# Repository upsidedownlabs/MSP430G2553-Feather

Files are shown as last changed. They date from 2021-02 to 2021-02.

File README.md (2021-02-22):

# MSP430G2553 Feather Board

  

MSP430G2553 based Adafruit feather compatible board 🪶

| Front |  Back |
| :---: | :---: |
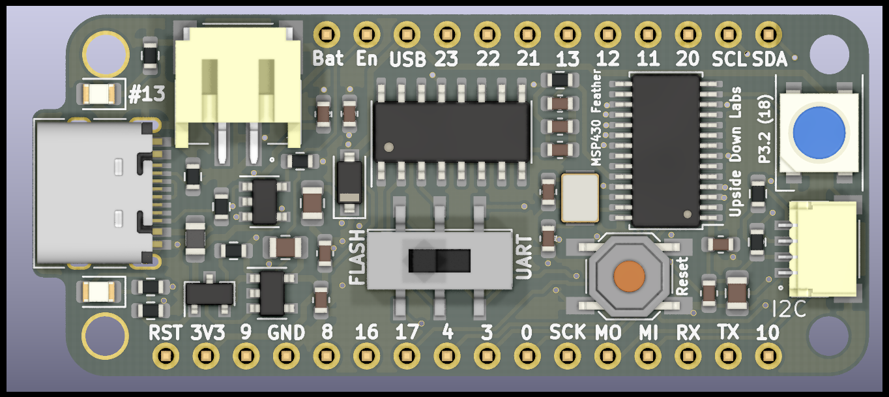
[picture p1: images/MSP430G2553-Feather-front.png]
Upside Down Labs MSP430G2553 Feather front
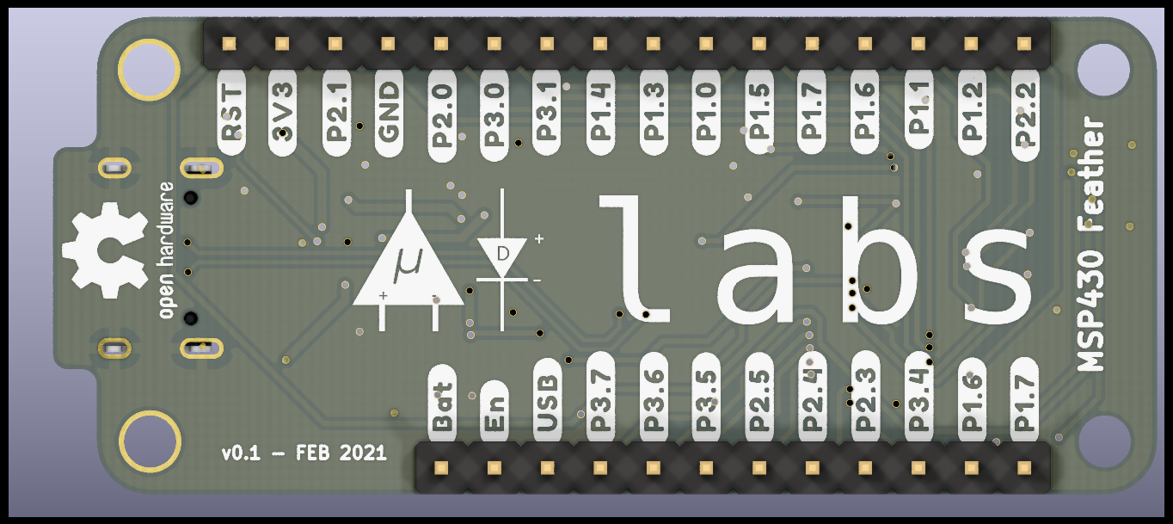
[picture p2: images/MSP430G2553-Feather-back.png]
Upside Down Labs MSP430G2553 Feather back
|   |  |

<!-- |Pinout|
| :--: |
|![Upside Down Labs MSP430G2553 Feather front](/images/MSP430G2553-Feather-Pinout.png)| -->

| Dimensions |  Schematic |
| :---: | :---: |
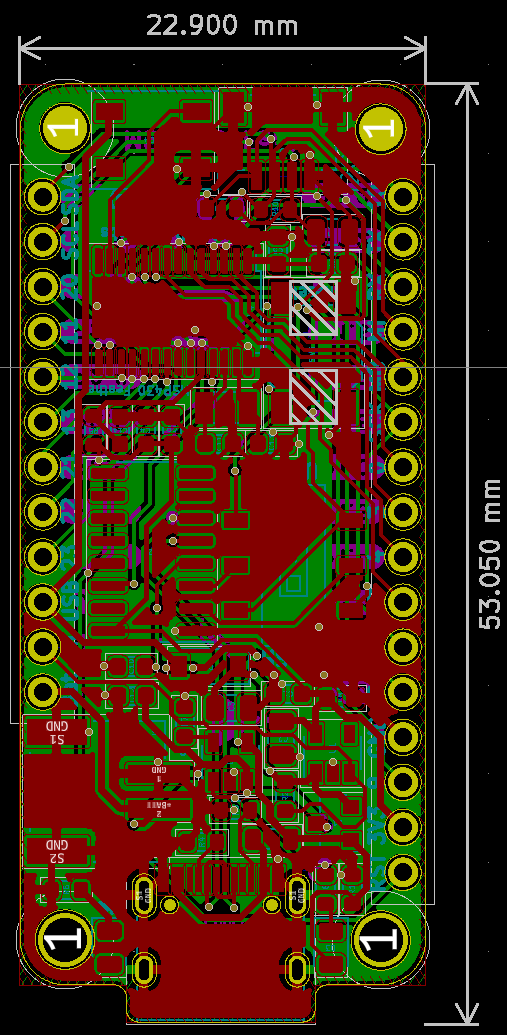
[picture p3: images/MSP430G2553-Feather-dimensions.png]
Upside Down Labs MSP430G2553 Feather dimensions
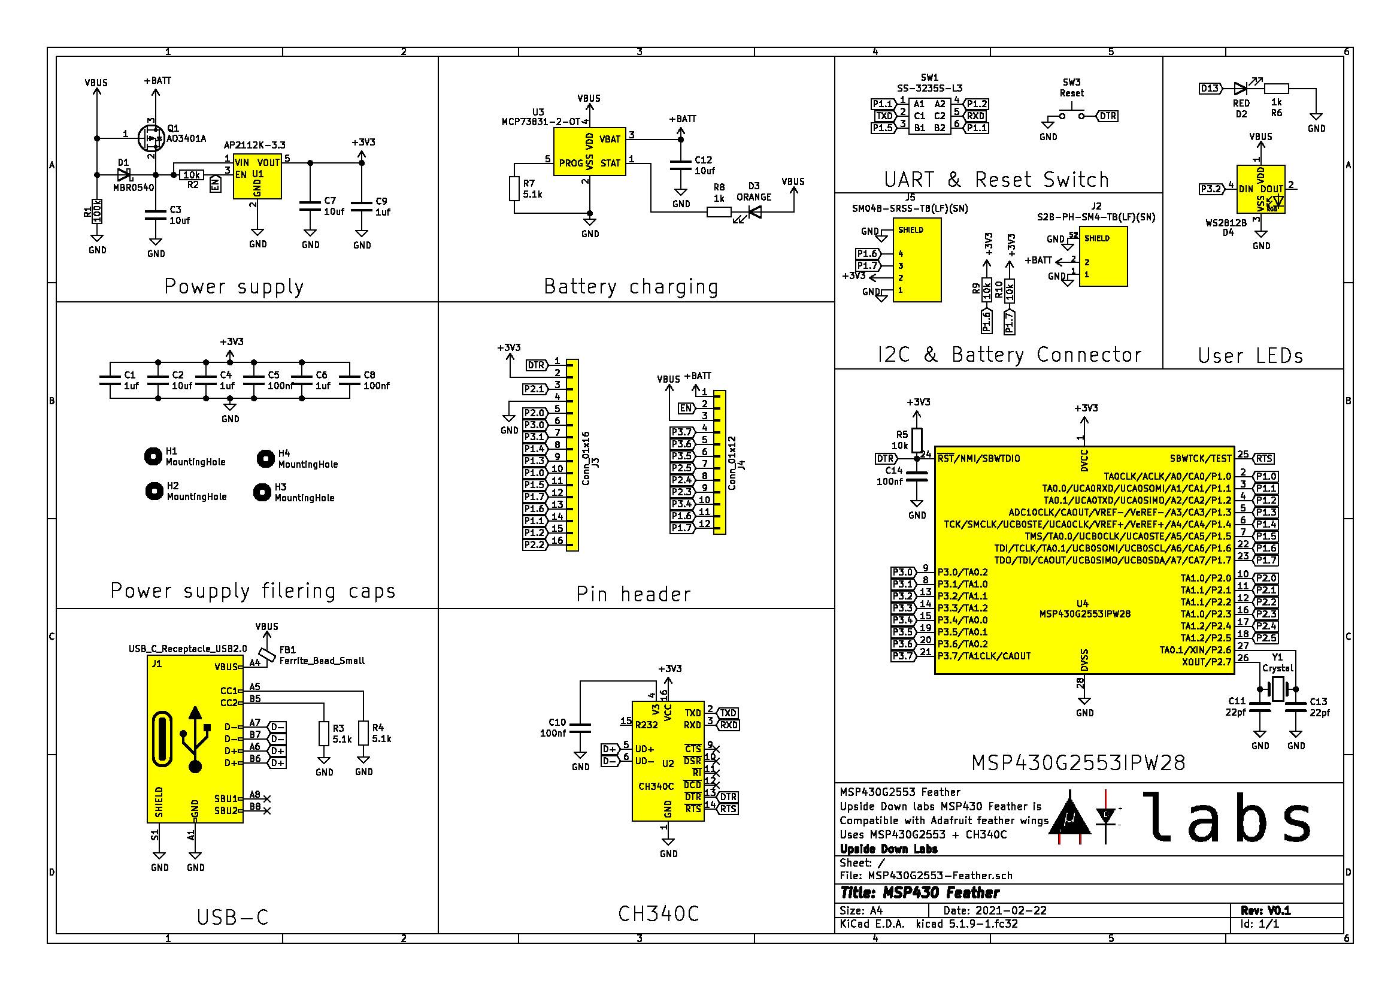
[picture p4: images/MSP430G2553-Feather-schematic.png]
Upside Down Labs MSP430G2553 Feather schematic
| 53.05 x 22.90 mm  |  |

## License

#### Hardware
CERN Open Hardware License Version 2 - Strongly Reciprocal ([CERN-OHL-S-2.0](https://spdx.org/licenses/CERN-OHL-S-2.0.html)).

#### Software
MIT open source [license](http://opensource.org/licenses/MIT).

#### Documentation:
<br />This work is licensed under a <a rel="license" href="http://creativecommons.org/licenses/by/4.0/">Creative Commons Attribution 4.0 International License</a>.

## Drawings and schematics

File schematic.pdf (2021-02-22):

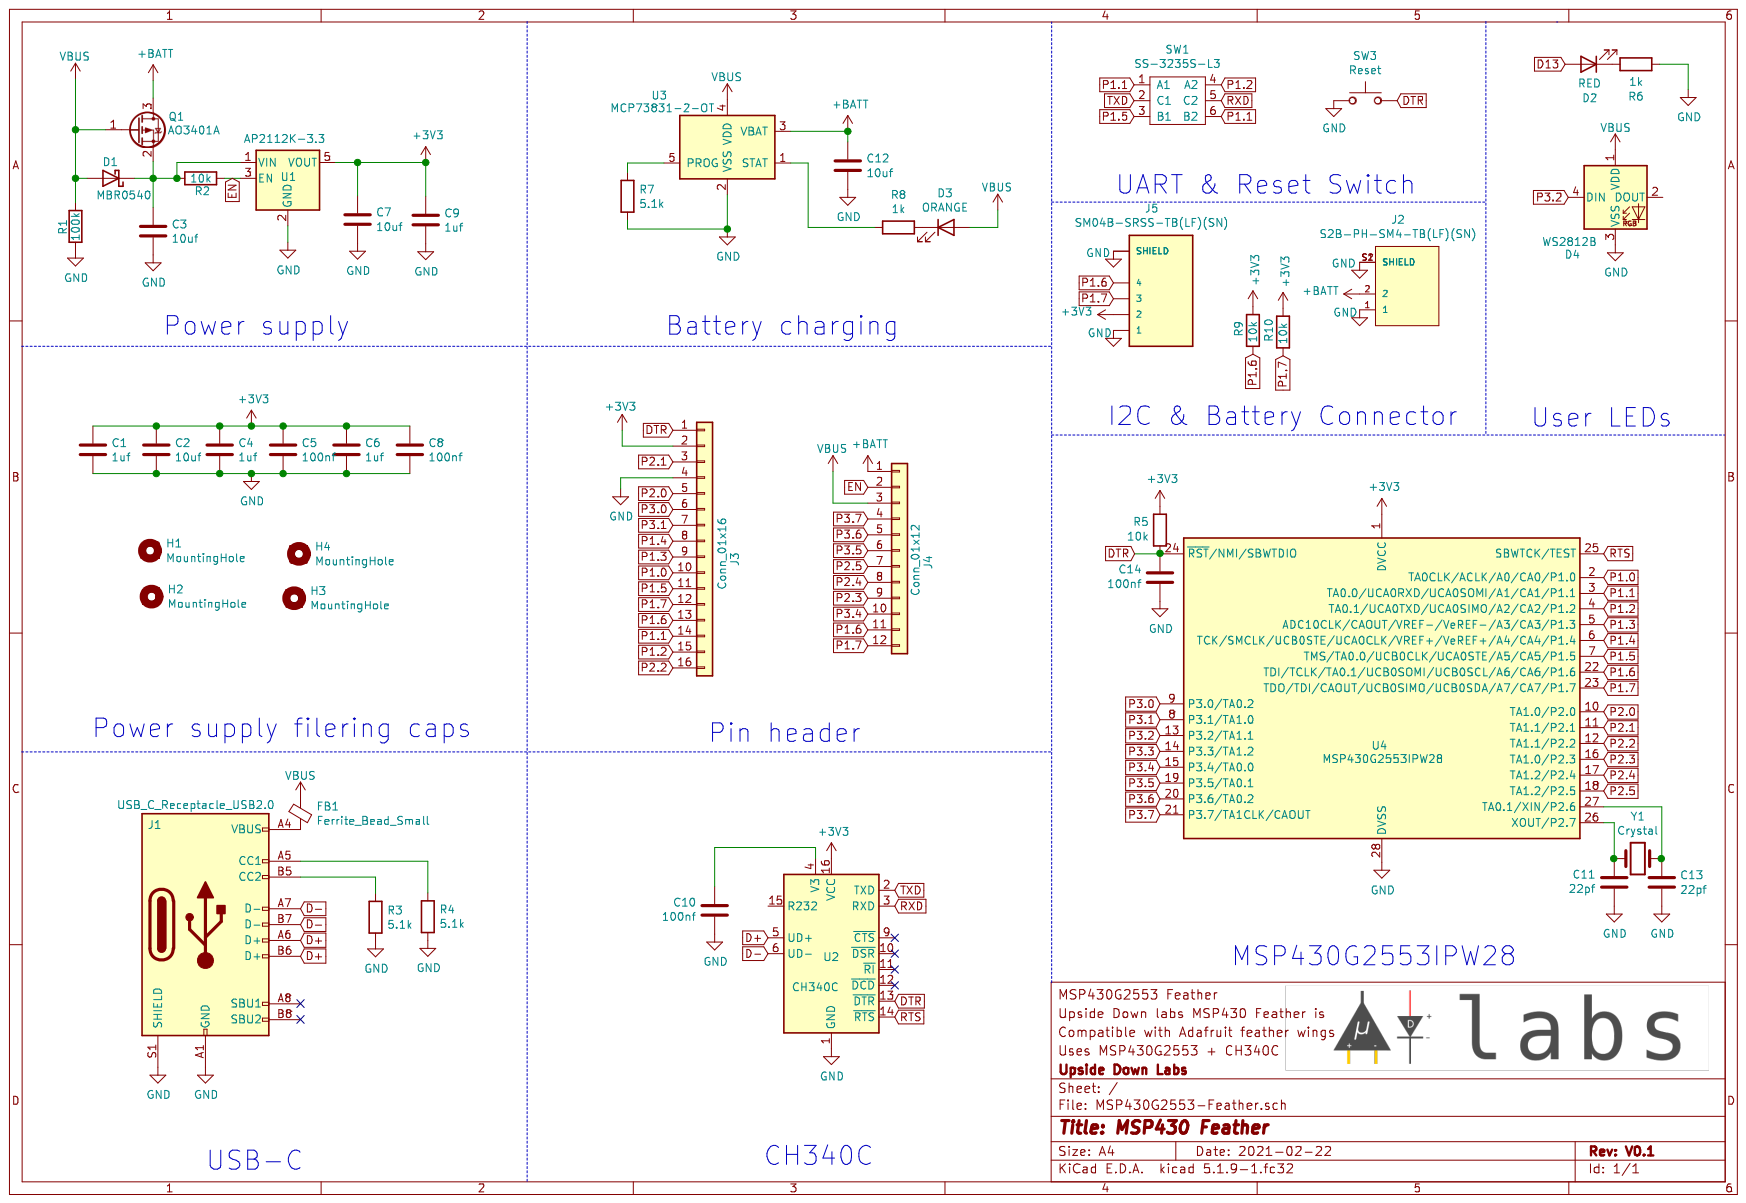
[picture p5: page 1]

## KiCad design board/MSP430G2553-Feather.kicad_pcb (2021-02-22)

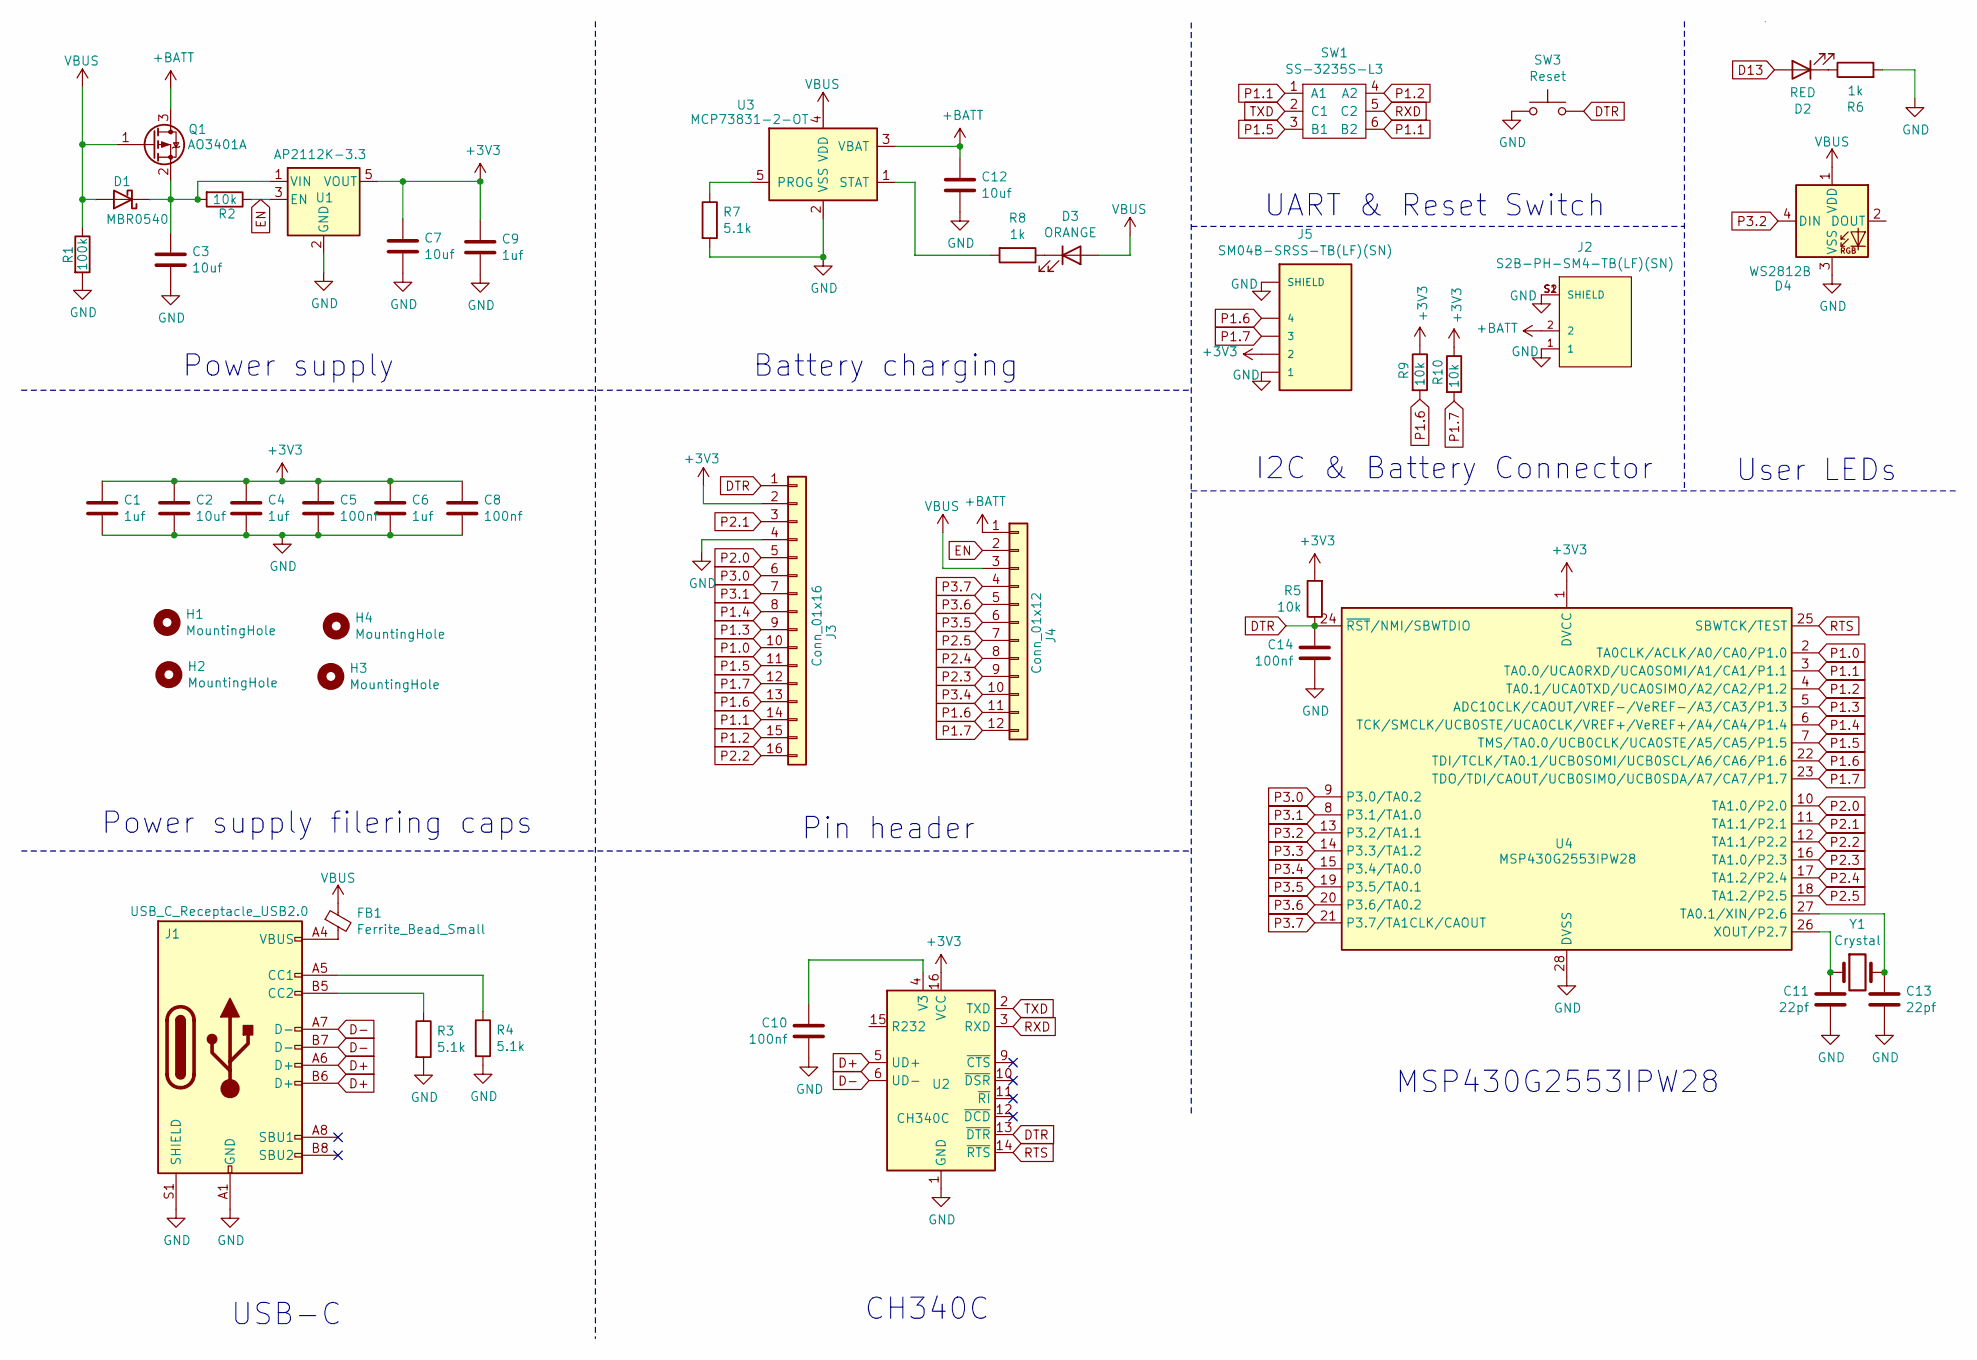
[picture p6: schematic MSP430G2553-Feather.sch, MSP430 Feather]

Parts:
C1, C4, C6, C9: 1uf; C_0603_1608Metric
C2, C3, C7: 10uf; C_0805_2012Metric
C5, C8, C10, C14: 100nf; C_0603_1608Metric
C11, C13: 22pf; C_0603_1608Metric
C12: 10uf; C_0603_1608Metric
D1: MBR0540; D_SOD-123
D2: RED; LED_0805_2012Metric
D3: ORANGE; LED_0805_2012Metric
D4: WS2812B; LED_WS2812B_PLCC4_5.0x5.0mm_P3.2mm
FB1: Ferrite_Bead_Small; L_0805_2012Metric
H1, H2: MountingHole; MountingHole_2.5mm
H3, H4: MountingHole; MountingHole_2.5mm_Pad
J1: USB_C_Receptacle_USB2.0; USB_C_Receptacle_HRO_TYPE-C-31-M-12
J2: S2B-PH-SM4-TB(LF)(SN); JST_S2B-PH-SM4-TB(LF)(SN)
J3: Conn_01x16; PinHeader_1x16_P2.54mm_Vertical
J4: Conn_01x12; PinHeader_1x12_P2.54mm_Vertical
J5: SM04B-SRSS-TB(LF)(SN); JST_SM04B-SRSS-TB(LF)(SN)
Q1: AO3401A; SOT-23
R1: 100k; R_0603_1608Metric
R2, R5, R9, R10: 10k; R_0603_1608Metric
R3, R4, R7: 5.1k; R_0603_1608Metric
R6, R8: 1k; R_0603_1608Metric
SW1: SS-3235S-L3
SW3: Reset; SW_SPST_SKQG_WithStem
U1: AP2112K-3.3; SOT-23-5
U2: CH340C; SOIC-16_3.9x9.9mm_P1.27mm
U3: MCP73831-2-OT; SOT-23-5
U4: MSP430G2553IPW28; TSSOP-28_4.4x9.7mm_P0.65mm
Y1: Crystal; Crystal_SMD_3215-2Pin_3.2x1.5mm

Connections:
+3V3: C1.1, C2.1, C4.1, C5.1, C6.1, C7.1, C8.1, C9.1, J3.2, J5.2, R5.2, R9.1, R10.1, U1.5 (VOUT), U2.16 (VCC), U4.1 (DVCC)
+BATT: C12.1, J2.2, J4.1, Q1.3 (D), U3.3 (VBAT)
D13: D2.2 (A)
D+: J1.A6 (D+), J1.B6 (D+), U2.5 (UD+)
D-: J1.A7 (D-), J1.B7 (D-), U2.6 (UD-)
DTR: C14.2, J3.1, R5.1, SW3.2, U2.13 (~DTR), U4.24 (~RST~/NMI/SBWTDIO)
EN: J4.2, R2.1, U1.3 (EN)
GND: C1.2, C2.2, C3.2, C4.2, C5.2, C6.2, C7.2, C8.2, C9.2, C10.1, C11.1, C12.2, C13.2, C14.1, D4.3 (VSS), J1.A1 (GND), J1.A12 (GND), J1.B1 (GND), J1.B12 (GND), J1.S1 (SHIELD), J2.1, J2.S1 (SHIELD), J2.S2 (SHIELD), J3.4, J5.1, J5.S1 (SHIELD), J5.S2 (SHIELD), R1.2, R3.2, R4.2, R6.2, R7.2, SW3.1, U1.2 (GND), U2.1 (GND), U3.2 (VSS), U4.28 (DVSS)
unnamed: C3.1, D1.1 (K), Q1.2 (S), R2.2, U1.1 (VIN)
unnamed: C10.2, U2.4 (V3)
unnamed: C11.2, U4.26 (XOUT/P2.7), Y1.1
unnamed: C13.1, U4.27 (TA0.1/XIN/P2.6), Y1.2
unnamed: D2.1 (K), R6.1
unnamed: D3.1 (K), R8.1
unnamed: FB1.2, J1.A4 (VBUS), J1.A9 (VBUS), J1.B4 (VBUS), J1.B9 (VBUS)
unnamed: J1.A5 (CC1), R4.1
unnamed: J1.B5 (CC2), R3.1
unnamed: R7.1, U3.5 (PROG)
unnamed: R8.2, U3.1 (STAT)
P1.0: J3.10, U4.2 (TA0CLK/ACLK/A0/CA0/P1.0)
P1.1: J3.14, SW1.1 (A1), SW1.6 (B2), U4.3 (TA0.0/UCA0RXD/UCA0SOMI/A1/CA1/P1.1)
P1.2: J3.15, SW1.4 (A2), U4.4 (TA0.1/UCA0TXD/UCA0SIMO/A2/CA2/P1.2)
P1.3: J3.9, U4.5 (ADC10CLK/CAOUT/VREF-/VeREF-/A3/CA3/P1.3)
P1.4: J3.8, U4.6 (TCK/SMCLK/UCB0STE/UCA0CLK/VREF+/VeREF+/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)
P1.5: J3.11, SW1.3 (B1), U4.7 (TMS/TA0.0/UCB0CLK/UCA0STE/A5/CA5/P1.5)
P1.6: J3.13, J4.11, J5.4, R9.2, U4.22 (TDI/TCLK/TA0.1/UCB0SOMI/UCB0SCL/A6/CA6/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)
P1.7: J3.12, J4.12, J5.3, R10.2, U4.23 (TDO/TDI/CAOUT/UCB0SIMO/UCB0SDA/A7/CA7/P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)
P2.0: J3.5, U4.10 (TA1.0/P2.0)
P2.1: J3.3, U4.11 (TA1.1/P2.1)
P2.2: J3.16, U4.12 (TA1.1/P2.2)
P2.3: J4.9, U4.16 (TA1.0/P2.3)
P2.4: J4.8, U4.17 (TA1.2/P2.4)
P2.5: J4.7, U4.18 (TA1.2/P2.5)
P3.0: J3.6, U4.9 (P3.0/TA0.2)
P3.1: J3.7, U4.8 (P3.1/TA1.0)
P3.2: D4.4 (DIN), U4.13 (P3.2/TA1.1)
P3.3: U4.14 (P3.3/TA1.2)
P3.4: J4.10, U4.15 (P3.4/TA0.0)
P3.5: J4.6, U4.19 (P3.5/TA0.1)
P3.6: J4.5, U4.20 (P3.6/TA0.2)
P3.7: J4.4, U4.21 (P3.7/TA1CLK/CAOUT)
RTS: U2.14 (~RTS), U4.25 (SBWTCK/TEST)
RXD: SW1.5 (C2), U2.3 (RXD)
TXD: SW1.2 (C1), U2.2 (TXD)
VBUS: D1.2 (A), D3.2 (A), D4.1 (VDD), FB1.1, J4.3, Q1.1 (G), R1.1, U3.4 (VDD)

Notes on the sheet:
User LEDs
I2C & Battery Connector
UART & Reset Switch
Battery charging
Power supply
Power supply filering caps
Pin header
CH340C
USB-C
MSP430G2553IPW28

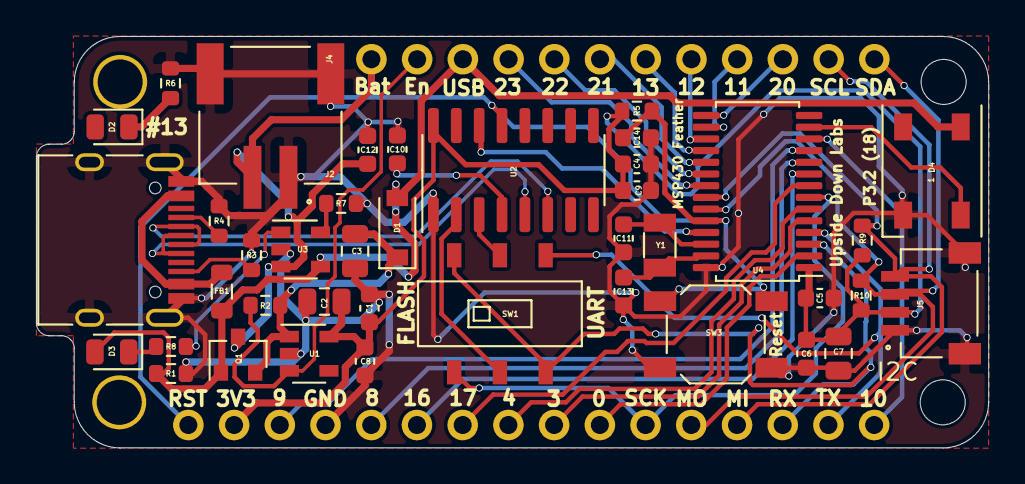
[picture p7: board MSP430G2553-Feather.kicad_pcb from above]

Board: 2 copper layers, 52.9 x 22.9 mm, 46 parts (0 on the bottom side), 43 nets.

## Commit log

2021-02-22 upload MSP430G2554 Feather board KiCAD files
    [MSP430G2553-Feather.kicad_pcb, MSP430G2553-Feather.sch]
2021-02-22 MSP430G2553 Feather v0.1 schematic
2021-02-22 add MSP430G2553 Feather Schematic
